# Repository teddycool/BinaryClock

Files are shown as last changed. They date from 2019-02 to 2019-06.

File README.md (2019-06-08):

# BinaryClock
A project to create a binary clock with a specially designed circuit-board and a raspberrypi zero

This project contains of several parts:
    * The circuitboard, made in Eagle CAD 
    * Raspberrypi code in python 2.7 written in PyCharm Community edition.
    * 3d models for a 3d-printed to the enclosure, made with tinkercad

Assembled and mounted in the 3d-printed enclosure:

The circuit board is a 'hat' to a raspberry pi zero with 20 WS2812B programmable LEDs for the clock-display, a 2x20 header
for the pi connection and some extra IOs and buttons. The board was manufactured by https://aisler.net that has a great quality service for small series of prototypes. 

The code depend on https://github.com/rpi-ws281x/rpi-ws281x-python Install this first.

It is a very simple 'game-loop' kind of program that updates every 1/5 second. Taking current time and  split to each figure (collumn) and then calculate  the bit-pattern and set the LEDs accordingly.

A simple user-manual and a technical description can be found in the project directory..

Future sw-improvements will add possibillities to configure colors and brightnes etc from outside.

Hardware version 3 is now ready and added a real-time clock directly on the circuitboard, some IOs to be controled by time, some extra buttons and a circuit for measuring the background light. 

Future hw-improvements will be to move the buttons to a better position when using the enclosure. 

Ref1: https://en.wikipedia.org/wiki/Binary_clock
Ref2: https://www.raspberrypi-spy.co.uk/2015/05/adding-a-ds3231-real-time-clock-to-the-raspberry-pi/

See pictures below for an other type of assembly with plexiglass as a 'sandwich'.

Pictures of hw version 1:
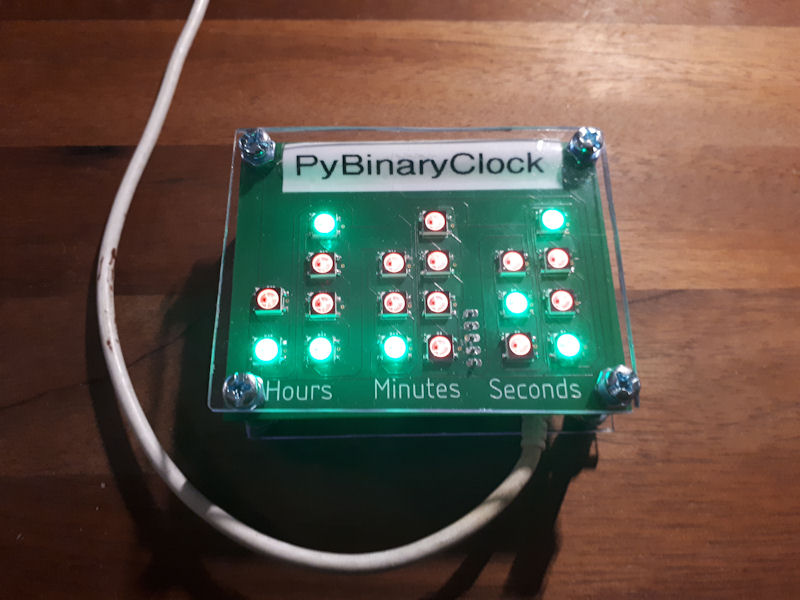
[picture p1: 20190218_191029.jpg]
Front...


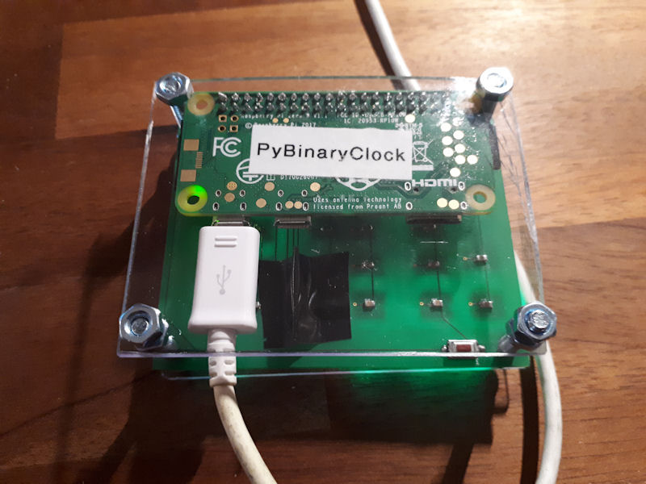
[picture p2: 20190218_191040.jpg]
Rear...


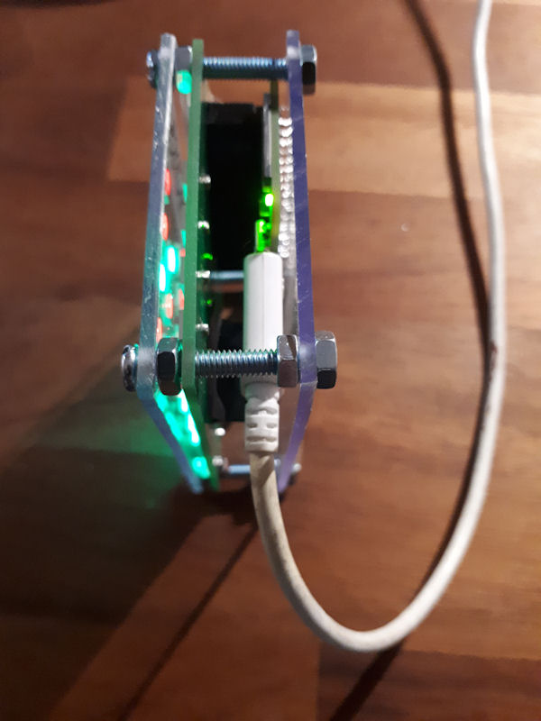
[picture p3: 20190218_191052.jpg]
Side...


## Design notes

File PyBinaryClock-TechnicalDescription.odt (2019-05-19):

The PyBinaryClock

# Technical description

The circuit board is a type of 'hat' to a raspberry pi zero with 20 WS2812B programmable LEDs for the clock-display, a 2x20 header for the pi connection and a real-time clock circuit. The board was manufactured by https://aisler.net that has a great quality service for small series of prototypes.

The kit is mounted between two part of plexi-glass panels to make a clock that can be mounted on the wall or put on a table. See pictures below.

## The hardware:

### Raspberry Pi zero W

- Install rasbian light and configure it for your localization etc.
- Enable the I2C interface: https://www.raspberrypi-spy.co.uk/2014/11/enabling-the-i2c-interface-on-the-raspberry-pi/
- Install the RTC clock module software and set it up the properly. Follow this guide: https://www.raspberrypi-spy.co.uk/2015/05/adding-a-ds3231-real-time-clock-to-the-raspberry-pi/ but be aware of that hardware is already present on the circuit-board in a correct way.
- Get the python lib for WS281x programmable leds: https://github.com/rpi-ws281x/rpi-ws281x-python
- Get the software for the binary clock from from github: https://github.com/teddycool/BinaryClock
- Fix autostart at boot, add these lines before 'exit' in /etc/rc.local
  - cd /home/pi/PyBinaryClock
  - sudo python Main.py

### Binary display

The circuit board design is presented in the 'Eagle' directory and version 3 of the board can be directly ordered from here: https://aisler.net/p/VFLSRFLZ

A bill of material is not compiled yet but all components are defined in the circuit diagram, also presented in the 'Eagle'-directory.

## The PyBinaryClock software:

The code depends on several libraries and the Raspberry Pi has to be set up for i2c, a real-time clock and ws281x among other things. Follow the hardware chapter above or the refs in the source-code to get going.

The work-horse of the software is a very simple 'game-loop'. Everything starts with running Main.py which in turn starts the MainLoop.py that initialize everything and then the update-method in this module is run over and over again.

The second important part is the state-machine. This sets a state depending on some prerequisites and the the current state is run by MainLoop.update.

The ClockLoop state updates the time and display every 1/5th of a second. Taking current time and split to each figure (column) and then calculate the bit-pattern and set the LEDs accordingly.

### Code structure

The software is split into several modules.

From top:

ClockStates is the state-machine with one base-class and inherited classes for each defined state.

Connectivity: These classes handles internet detection and WiFi setup etc.

IO: These classes handles the hardware of the clock-display. Each part of the hardware has its own class. The one with most code is the clock display itself (BinaryDisplay.py)

The Log and the WebConfig is not yet implemented.

The files in the 'root' is the startup file Main which calls MainLoop as described above.

### The State-machine

The clock starts in the 'init' state where network connection is checked and if there is a valid time present, either from the network or from the real-time clock.

If a valid time is detected the clock jumps to ClockLoop state and stays there until power off or if S1 is 'long-pressed'.

A valid time doesn't necessarily mean the correct time....

If no valid time is detected (no network connection and also no valid time from the real-time clock) the clock jumps to NoValidTime state. This state is kept until either a network is detected or Wps is set up via a long-press on S1.

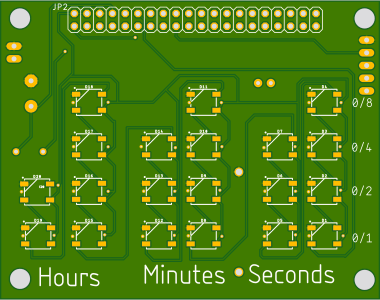
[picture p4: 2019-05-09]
cb_front_v3.jpg

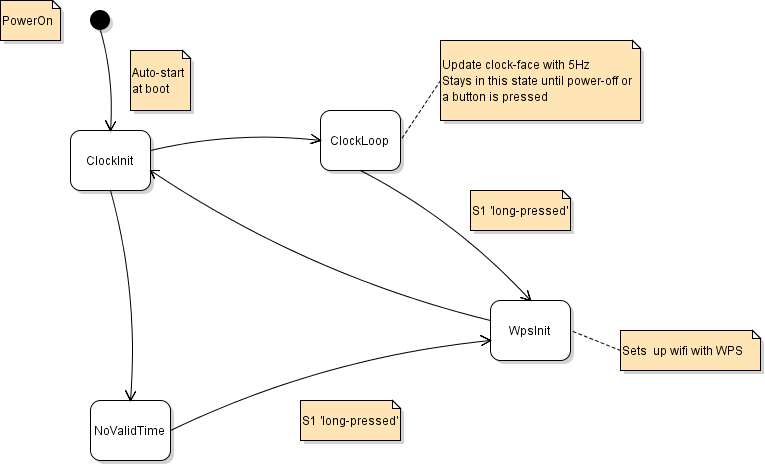
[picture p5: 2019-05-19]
ClockStates.png

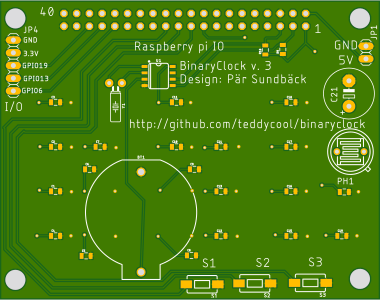
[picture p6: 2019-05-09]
cb_back_v3.jpg

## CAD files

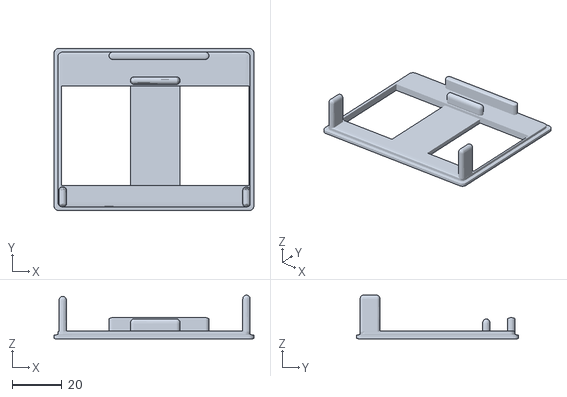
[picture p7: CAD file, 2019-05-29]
BinaryClockRear.stl
80.0 x 65.0 x 17.5

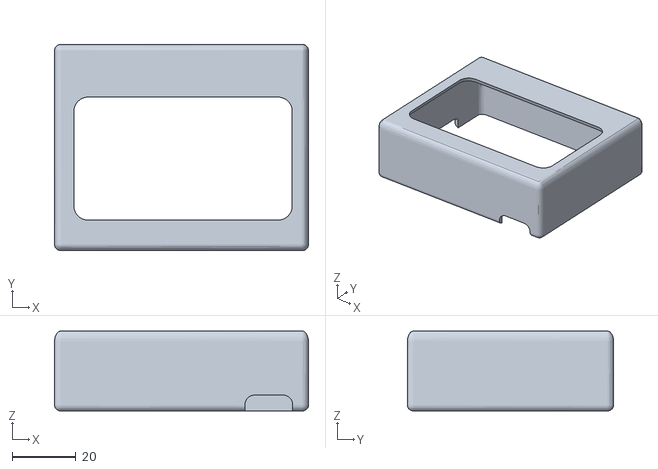
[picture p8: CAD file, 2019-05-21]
BinaryClockFace.stl
80.0 x 65.0 x 25.2

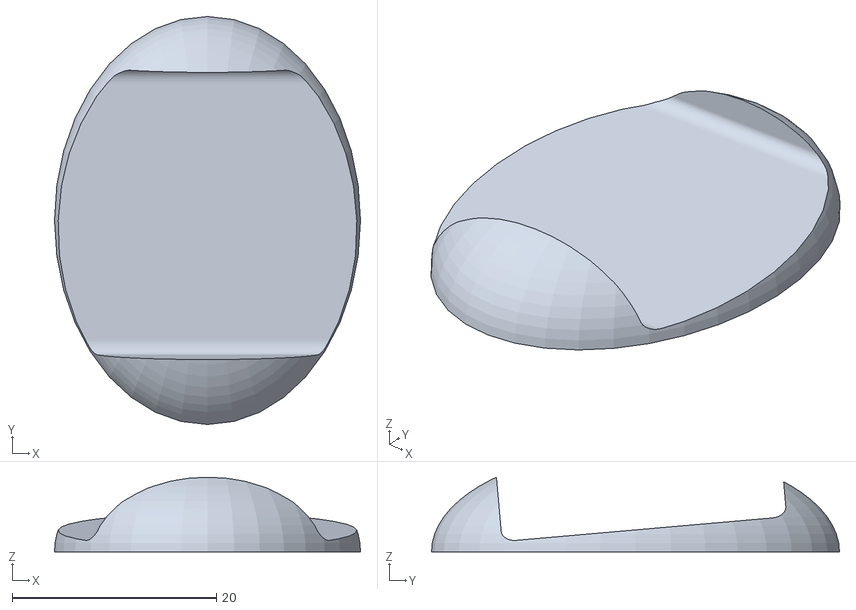
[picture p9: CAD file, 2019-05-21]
BinaryClockFoot.stl
30.0 x 40.0 x 7.31

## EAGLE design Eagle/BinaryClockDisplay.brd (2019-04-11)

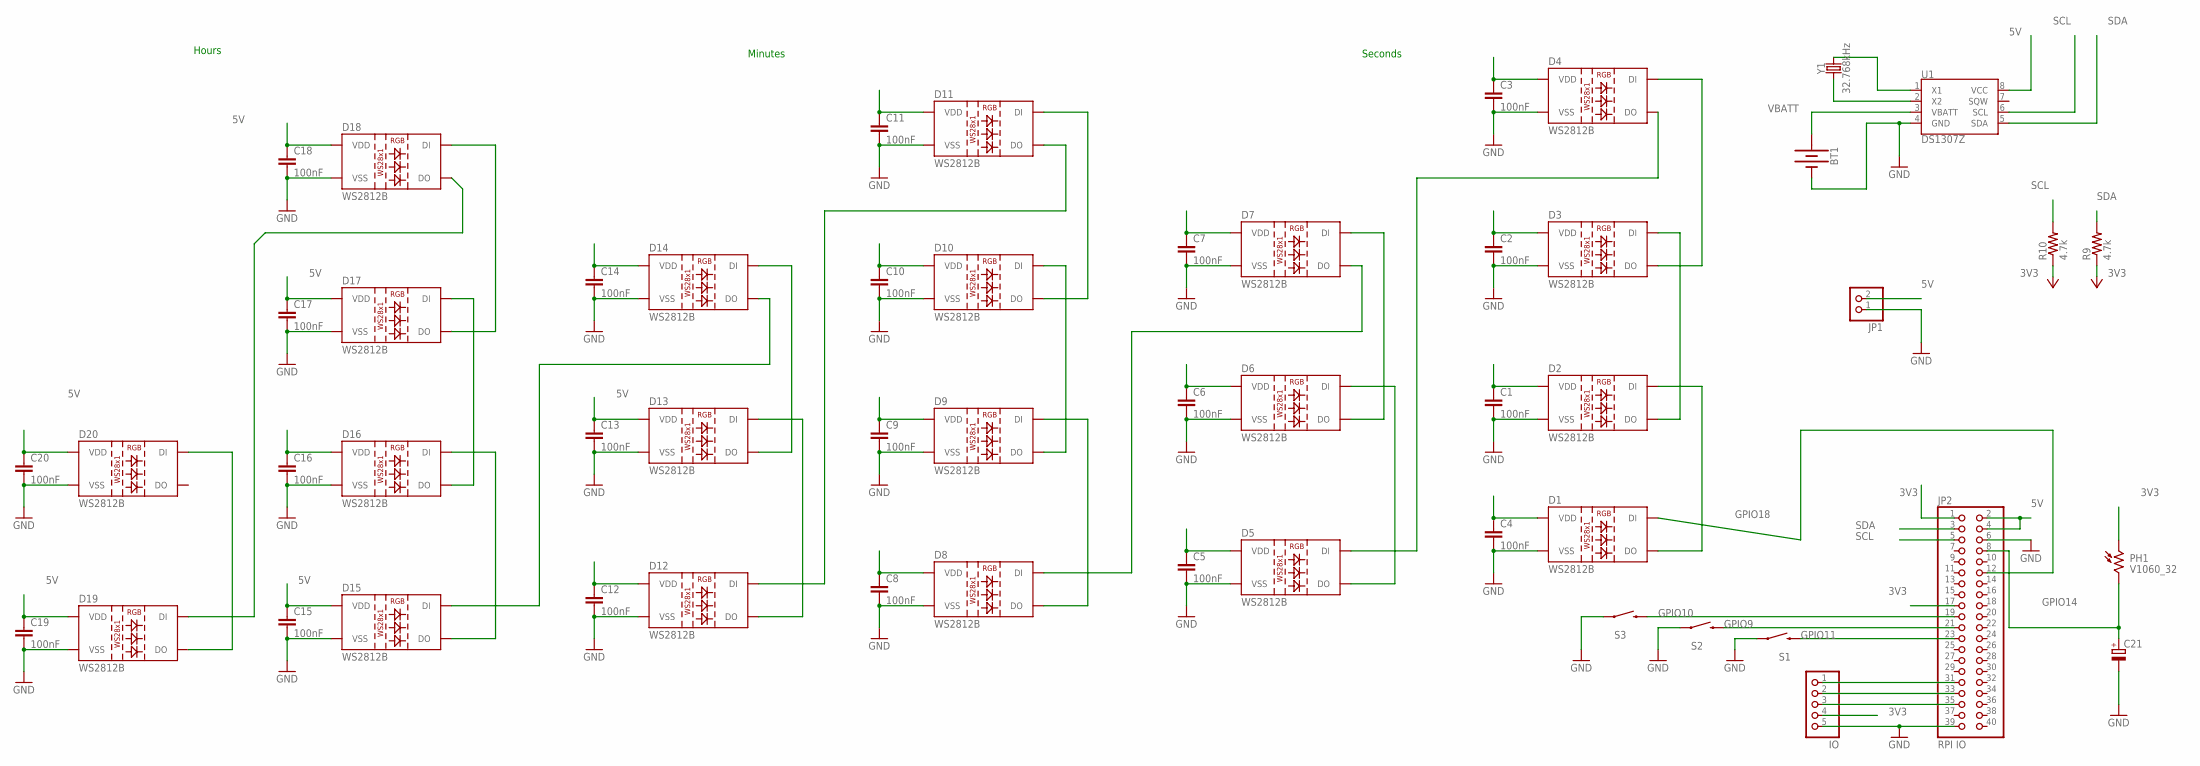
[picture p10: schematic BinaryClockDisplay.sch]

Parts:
BT1: BATTERY-20MM_PTH; BATTCOM_20MM_PTH
C1, C2, C3, C4, C5, C6, C7, C8, C9, C10, C11, C12, C13, C14, C15, C16, C17, C18, C19, C20: 100nF; 0805
C21: CPOL-EUE5-10.5; E5-10,5
D1, D2, D3, D4, D5, D6, D7, D8, D9, D10, D11, D12, D13, D14, D15, D16, D17, D18, D19, D20: WS2812B
JP1: PINHD-1X2; 1X02
JP2: RPI IO; 2X20
JP4: IO; 1X05
PH1: V1060_32; TO-5_V10
R9, R10: 4.7k; 0805
S1, S2, S3: SWITCH; TACTILE-SWITCH-1101NE
U1: DS1307Z; SO08-0.15
Y1: 32.768kHz; CRYSTAL-PTH-2X6-CYL

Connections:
3V3: JP2.1, JP2.17, JP4.4, PH1.1, R9.1, R10.1
5V: C1.1, C2.1, C3.1, C4.1, C5.1, C6.1, C7.1, C8.1, C9.1, C10.1, C11.1, C12.1, C13.1, C14.1, C15.1, C16.1, C17.1, C18.1, C19.1, C20.1, D1.1 (VDD), D2.1 (VDD), D3.1 (VDD), D4.1 (VDD), D5.1 (VDD), D6.1 (VDD), D7.1 (VDD), D8.1 (VDD), D9.1 (VDD), D10.1 (VDD), D11.1 (VDD), D12.1 (VDD), D13.1 (VDD), D14.1 (VDD), D15.1 (VDD), D16.1 (VDD), D17.1 (VDD), D18.1 (VDD), D19.1 (VDD), D20.1 (VDD), JP1.2, JP2.2, JP2.4, U1.8 (VCC)
GND: BT1.2 (-), C1.2, C2.2, C3.2, C4.2, C5.2, C6.2, C7.2, C8.2, C9.2, C10.2, C11.2, C12.2, C13.2, C14.2, C15.2, C16.2, C17.2, C18.2, C19.2, C20.2, C21.-, D1.3 (VSS), D2.3 (VSS), D3.3 (VSS), D4.3 (VSS), D5.3 (VSS), D6.3 (VSS), D7.3 (VSS), D8.3 (VSS), D9.3 (VSS), D10.3 (VSS), D11.3 (VSS), D12.3 (VSS), D13.3 (VSS), D14.3 (VSS), D15.3 (VSS), D16.3 (VSS), D17.3 (VSS), D18.3 (VSS), D19.3 (VSS), D20.3 (VSS), JP1.1, JP2.6, JP2.39, JP4.5, S1.1, S2.1, S3.1, U1.4 (GND)
GPIO6: JP2.31, JP4.1
GPIO9: JP2.21, S2.2
GPIO10: JP2.19, S3.2
GPIO11: JP2.23, S1.2
GPIO13: JP2.33, JP4.2
GPIO14: C21.+, JP2.8, PH1.2
GPIO18: D1.4 (DI), JP2.12
GPIO19: JP2.35, JP4.3
unnamed: D4.2 (DO), D5.4 (DI)
unnamed: D5.2 (DO), D6.4 (DI)
unnamed: D1.2 (DO), D2.4 (DI)
unnamed: D2.2 (DO), D3.4 (DI)
unnamed: D3.2 (DO), D4.4 (DI)
unnamed: U1.1 (X1), Y1.2
unnamed: D6.2 (DO), D7.4 (DI)
unnamed: D8.2 (DO), D9.4 (DI)
unnamed: D9.2 (DO), D10.4 (DI)
unnamed: D10.2 (DO), D11.4 (DI)
unnamed: D11.2 (DO), D12.4 (DI)
unnamed: D7.2 (DO), D8.4 (DI)
unnamed: D12.2 (DO), D13.4 (DI)
unnamed: D13.2 (DO), D14.4 (DI)
unnamed: D15.2 (DO), D16.4 (DI)
unnamed: D16.2 (DO), D17.4 (DI)
unnamed: D17.2 (DO), D18.4 (DI)
unnamed: D14.2 (DO), D15.4 (DI)
unnamed: U1.2 (X2), Y1.1
unnamed: D19.2 (DO), D20.4 (DI)
unnamed: D18.2 (DO), D19.4 (DI)
SCL: JP2.5, R10.2, U1.6 (SCL)
SDA: JP2.3, R9.2, U1.5 (SDA)
VBATT: BT1.1 (+), U1.3 (VBATT)

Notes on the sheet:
Hours
Minutes
Seconds

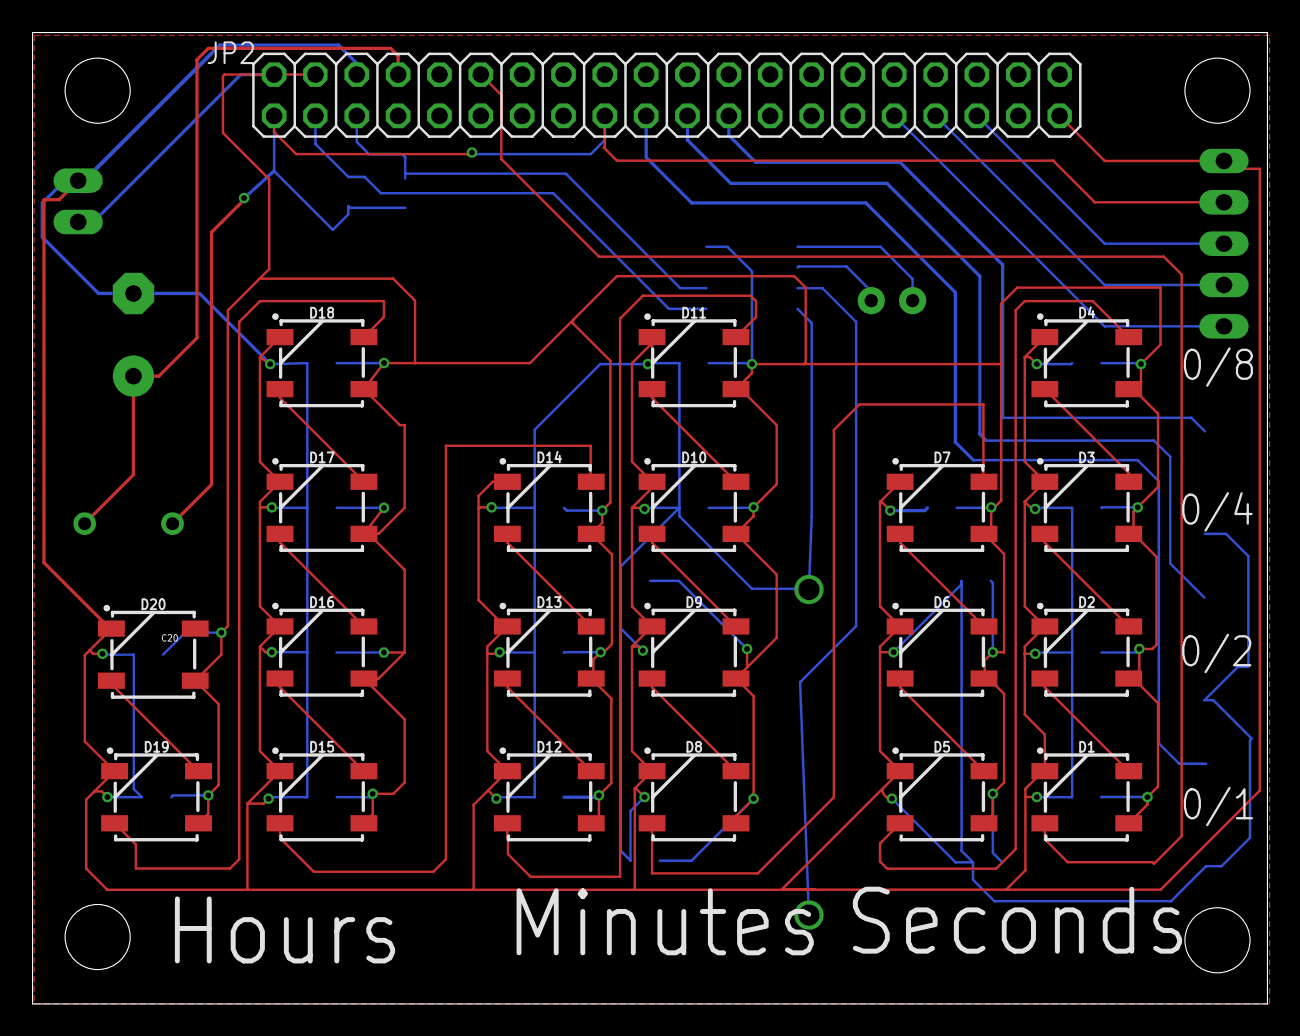
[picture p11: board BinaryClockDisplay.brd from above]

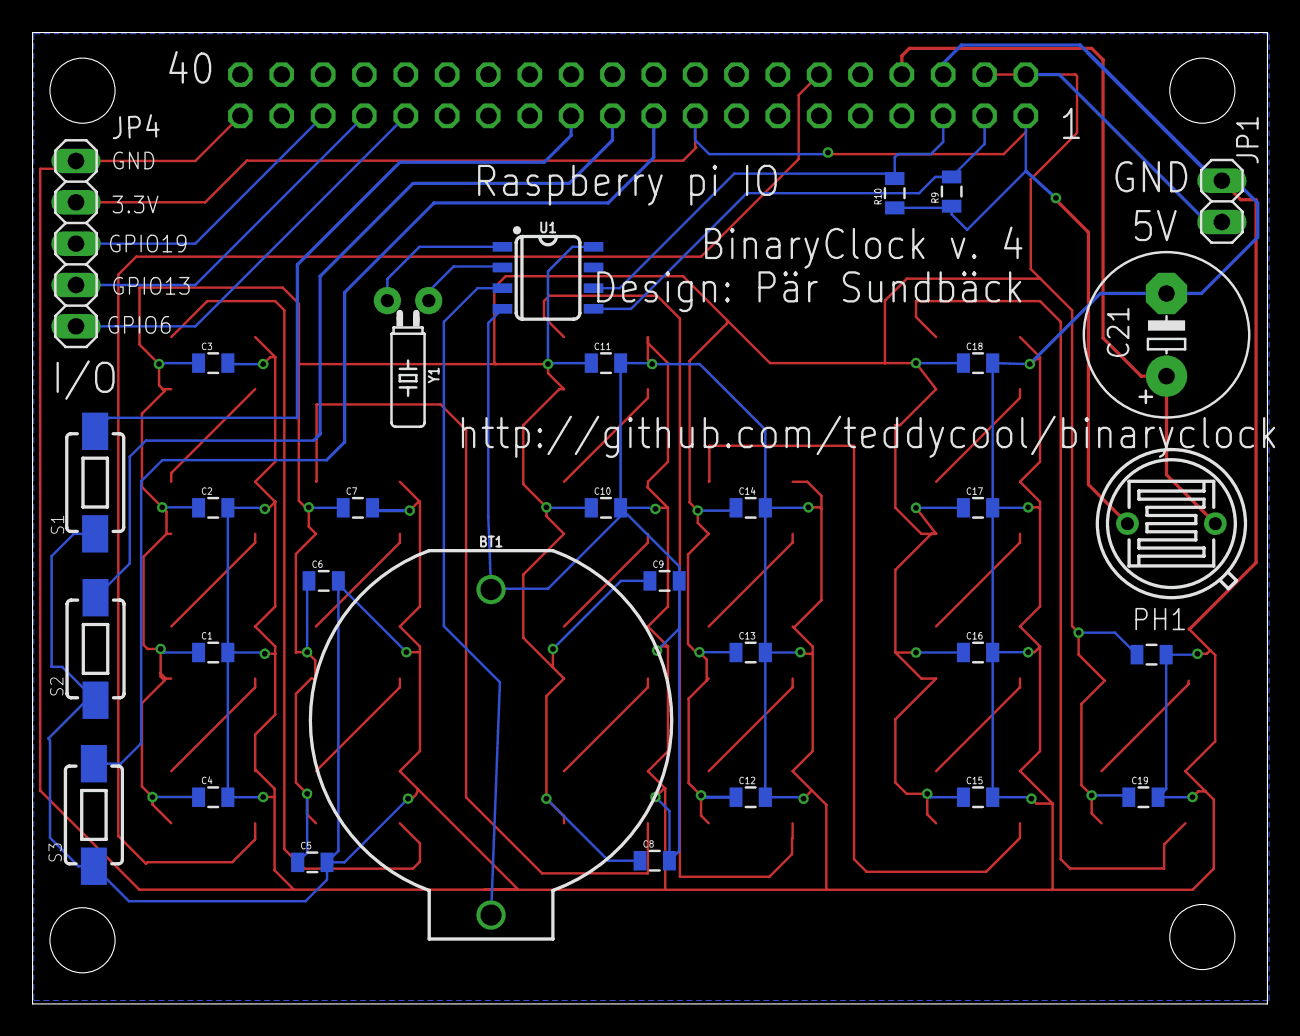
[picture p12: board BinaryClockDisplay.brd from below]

Board: 2 copper layers, 75.9 x 59.7 mm, 53 parts (32 on the bottom side), 35 nets.

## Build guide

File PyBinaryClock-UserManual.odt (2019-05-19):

The PyBinaryClock

User manual, version 2019.1

# Introduction

This is a binary clock with a specially designed circuit-board and a raspberry pi zero.

## How to read the time

The clock is in binary code with each figure as a column as HH:MM:SS.

A green led in the lowest row means '1' and in the next '2', '4' and '8' respectively. A red led means that this position is '0' and to get the correct time each figure is a sum of the positions with green leds in that row.

Example: The time is 18:48:36

## Connections, on the backside of the raspberry pi:

Power: 5V micro USB (phone charger)

I/O: Micro USB to USB, OTP cable for connecting keyboard/LAN/etc via USB

HDMI: Micro HDMI for a screen

## Buttons, on the backside of the circuit-board:

'Long-press'

S1: Set WiFi-connection-mode,

S2: not used yet

S3: not used yet

# Simple set-up of WLAN

This method can be used if you have a router with a 'WPS' button.

1. Start the clock and wait until a time-pattern is shown
2. Press S1 for at least 3 seconds .
3. The display switch to 'WPS-connection-mode' (all yellow for a short time) and starts to count by lighting one blue led at a time.
4. Press the 'WPS-button' on your router for a couple of seconds.
5. When the connection is established (it can take a minute), a led turns green and the the clock starts with the correct time for central European time.
6. The battery powered real-time clock is now also set to the correct time.

Github project page: https://github.com/teddycool/BinaryClock

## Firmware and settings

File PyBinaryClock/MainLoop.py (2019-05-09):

__author__ = 'teddycool'
#State-switching and handling of general rendering

import time
from IO import BinaryDisplay
from IO import IoInputs
from IO import TempMonitor
from IO import LightSensor
import os
from ClockStates import ClockInit
from ClockStates import ClockLoop
from ClockStates import WpsInitLoop
from ClockStates import NoTimeState


#Global GPIO used by all...
import RPi.GPIO as GPIO

class MainLoop(object):
    def __init__(self):
        self._gpio= GPIO
        self._gpio.setmode(self._gpio.BCM)
        self._binDisplay = BinaryDisplay.BinaryDisplay()
        self._s1 = IoInputs.PushButton(self._gpio, 11)  #S1: WiFi-setup
        self._s2 = IoInputs.PushButton(self._gpio, 9)   #S2:
        self._s3 = IoInputs.PushButton(self._gpio, 10)  #S3:
        self._tm = TempMonitor.TempMonitor()
        self._ls = LightSensor.LightSensor(self._gpio,14)
        self._states = {"ClockInit": ClockInit.ClockInit(), "ClockLoop": ClockLoop.ClockLoop(),
                        "WpsInit": WpsInitLoop.WpsInitLoop(),"NoValidTime": NoTimeState.NoTimeState()}

    def initialize(self):
        print "Mainloop initialize"
        self._s1.initialize()
        self._binDisplay.initialize()
        self._tm.initialize()
        self._binDisplay.SetBrightness(60)
        self._ls.initialize()

        self._lastUpdate = time.time()
        self._lastTempCheck = time.time()
        self._lastLightCheck=time.time()
        for state in self._states:
            self._states[state].initialize()
        self._setState("ClockInit")

    def update(self):
        #Logic for all states:

        # #Check if wifi button pressed


        #Check background ligth and set brigthness... normal 50, min 30 and max 80...
        ligth = int(self._ls.update())
        if ligth > 0:
            if ligth > 5:
                brightn = 40
            elif ligth < 3:
                brightn = 100
            else:
                brightn = 60
            self._binDisplay.SetBrightness(brightn)

        if time.time() - self._lastTempCheck > 10:
            temp = self._tm.get_cpu_temperature()
            self._lastTempCheck=time.time()
            print "CPU-temp: " + str(temp)
            if self._tm.get_cpu_temperature() > 60:
                self._binDisplay.off()
                print "High temp!"
                print "Shutting down..."
                f = file(time.asctime() + "temp.log", 'w')
                f.write("High temperature!")
                f.write(str(temp))
                f.close()
                time.sleep(5)
                os.system('sudo shutdown -h now')

        self._myState.update(self)


    def _setState(self, newstate):
        print "Switching state to : " + newstate
        self._myState=self._states[newstate]

    def __del__(self):
        self._binDisplay.off()
        self._gpio.cleanup()
        print "MainLoop cleaned up"

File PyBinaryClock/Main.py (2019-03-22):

__author__ = 'teddycool'

from MainLoop import MainLoop
import sys
import time
import os


class Main(object):

    def __init__(self):
        print "Init Main object..."
        self._mainloop =  MainLoop()


    def run(self):
        self._mainloop.initialize()
        running=True
        frames = 0
        print "BinaryClock Main starts running..."
        while running:
            try:
                self._mainloop.update()
            except(KeyboardInterrupt):
                running = False
                del(self._mainloop)
                print "User aborted..."
            except (Exception):
                running = False
                del (self._mainloop)
                e = sys.exc_info()
                t = time
                n = time.ctime()[11:13] + time.ctime()[14:16]
                s = str(n).rjust(4)
                f = file(time.asctime()+".log", 'w')
                for l in e:
                    f.write(str(l))
                #os.system('sudo halt')


if __name__ == "__main__":
    print 'Started from: Main.py,  if __name__ == "__main__" '
    gl=Main()
    gl.run()


#Put this in  /etc/rc.local for autostart at boot:
#cd /home/pi/PyBinaryClock
#sudo python Main.py &

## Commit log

2019-01-25 added files..
    [BinaryClockDisplay.brd, BinaryClockDisplay.sch]
2019-01-26 Saturday morning work..
    Added python skeletton code
    Fixed RPi IO in circuit. Not tested...
    [BinaryDisplay.py, IoInputs.py, Main.py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]
2019-01-26 Updated circuit board
    [BinaryClockDisplay.brd, BinaryClockDisplay.sch]
2019-01-27 Simplyfied design
    I decided to simmplify the design and make this a pure binary clock. Therefore I removed the interface to the 1602 display. I will look a bit cooler as binary only ;-)
    [BinaryClockDisplay.brd, BinaryClockDisplay.sch]
2019-01-27 First version of complete board
2019-01-30 Adjusted schematics and circuit-board
    [BinaryClockDisplay.brd, BinaryClockDisplay.sch]
2019-02-03 Circuitboard as ordered from Aisler 2019-02-03
    Also a
    [BinaryClockDisplay.brd, BinaryClockDisplay.sch]
2019-02-15 Working code
    First version of code that shows the correct time.
    [BinaryDisplay.py, IoInputs.py, Main.py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]
2019-02-16 HW version 2
    [BinaryClockDisplay.brd]
2019-02-16 Text added to version 2
    [BinaryClockDisplay.brd]
2019-02-16 Fixed code
    See Main.py how to autostart the clock at power on
    [BinaryDisplay.py, Main.py, MainLoop.py]
2019-02-16 Create PyBinaryClockHWv2
    Image of new version of PCB. Not yet tested!
2019-02-17 Cleaning out some unused files
    [BinaryClockDisplay.brd, BinaryClockDisplay.sch]
2019-02-17 More fix and a temperature check turning off the pi if too hot
    [BinaryClockDisplay.brd]
2019-02-19 HW version 2 allmost done...
    [BinaryClockDisplay.brd, BinaryClockDisplay.sch]
2019-03-06 Circuitboard v.2 as ordered from Aisler
    The code for the new harware only partly updated
    [BinaryClockDisplay.brd]
2019-03-22 Started working with sw for v 2
    A real state-machine and some structural changes.
    [BinaryClockDisplay.brd, BinaryClockDisplay.sch]
2019-04-11 Working state machine
    Now with a working state-machine for clock-init, clock-loop and WiFi-setup. If not connected, the WPS setup is started and the pi is connected when the WPS push-button on the router ispressed.
    The brightness of the display is also set depending on background light.
2019-04-11 HW version 4
    Hardware version 4, not yet ordered. Only differnce from v 3 is the placement of the push-buttons.
    [BinaryClockDisplay.brd, BinaryClockDisplay.sch]
2019-05-09 Added start for webconfig
    [BinaryClockDisplay.sch]
2019-05-19 Documentation
    Updated the documentation and also added 3d printable modells for a first version of a cover.
    [BinaryClockFacex20.stl, BinaryClockFacex25.stl, BinaryClockRear.stl]
2019-05-21 Added new 3d-print models for enclosure
    [BinaryClockFace.stl, BinaryClockFacex20.stl, BinaryClockFacex25.stl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]

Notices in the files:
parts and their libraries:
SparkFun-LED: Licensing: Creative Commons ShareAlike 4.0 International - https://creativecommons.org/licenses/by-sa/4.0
